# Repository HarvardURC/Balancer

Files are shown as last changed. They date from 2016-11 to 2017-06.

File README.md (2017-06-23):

# Balancer
Repository for the Harvard Undergraduate Robotics Club's Balancer team

# CAD_Files
Contains CAD files used to create the Balancer. 

- 1X CAD contains files used to create our original Balancer
- 1.5X CAD contains files used to create our Balancer scaled up by 50%

# Final_Code
Contains our final competition code.

# Old NRF Code (also Filtering)
Contains deprecated code when from we used NRF communication protocol. Also contains deprecated code which used a complementary filter to smooth BNO sensor data. 

# Telemetry
Contains the TelemetryViewer app and txt files to setup our telemetry environment.

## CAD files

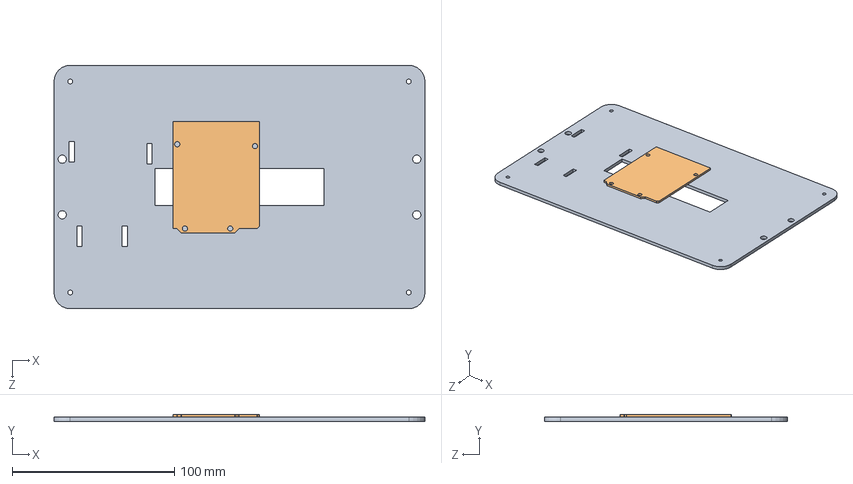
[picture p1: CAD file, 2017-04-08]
CAD_Files/1.5x CAD/new_layer.SLDASM
228.6 x 4.19 x 150.0 mm
new_layer
Arduino

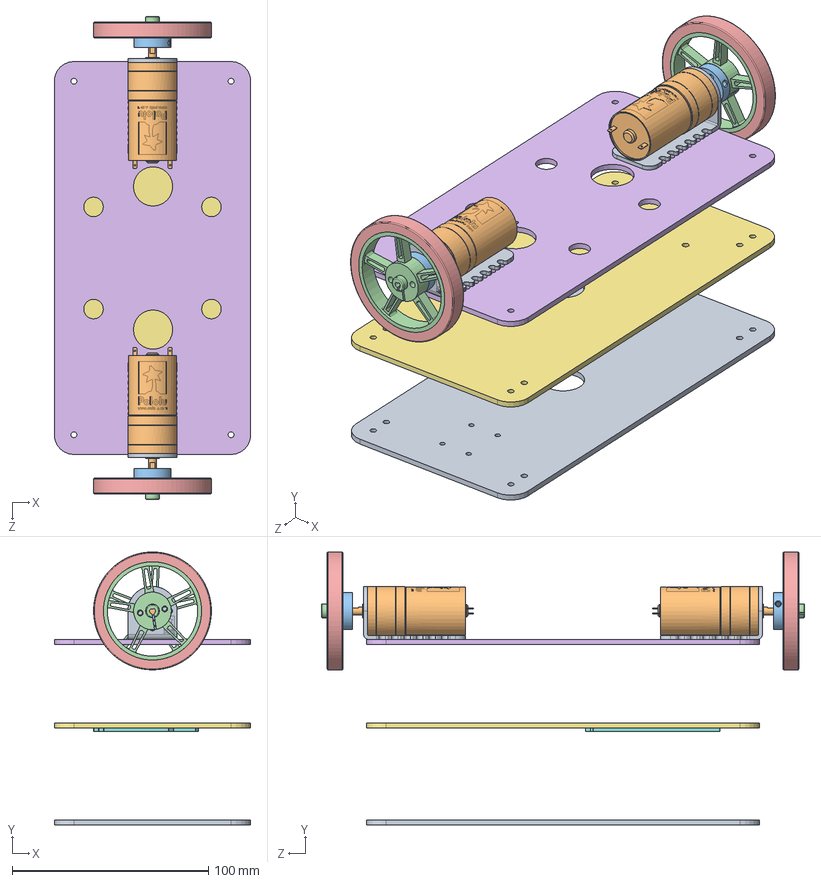
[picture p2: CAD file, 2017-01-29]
CAD_Files/1X CAD/full assembly.SLDASM
100.0 x 138.9 x 246.1 mm
motor mount x 2
motor x 2
mounting hub x 2
Part2^pololu wheel x 2
Part3^pololu wheel x 2
top
mid
Arduino
3rd layer

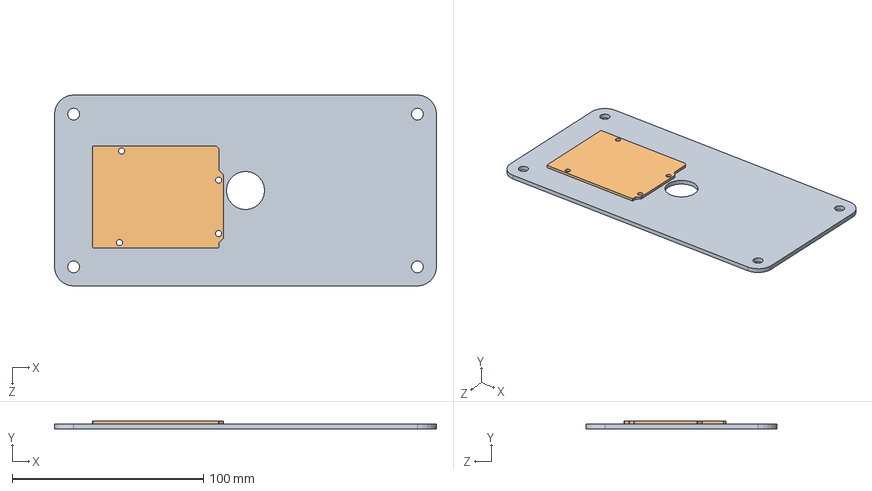
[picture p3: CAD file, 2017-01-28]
CAD_Files/1X CAD/mid assembly.SLDASM
200.0 x 4.19 x 100.0 mm
mid
Arduino

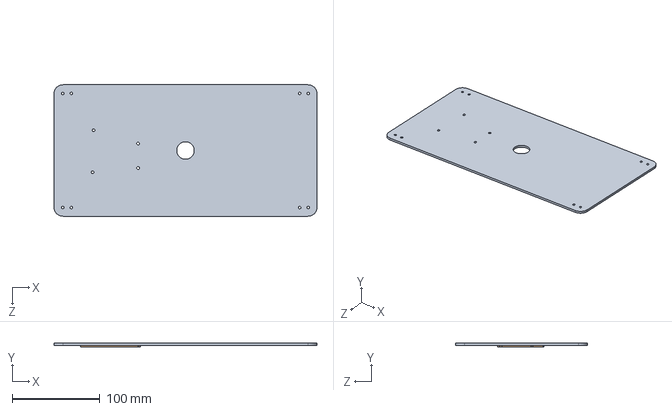
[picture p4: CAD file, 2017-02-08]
CAD_Files/1.5x CAD/mid assembly.SLDASM
300.0 x 4.19 x 150.0 mm
mid
Arduino

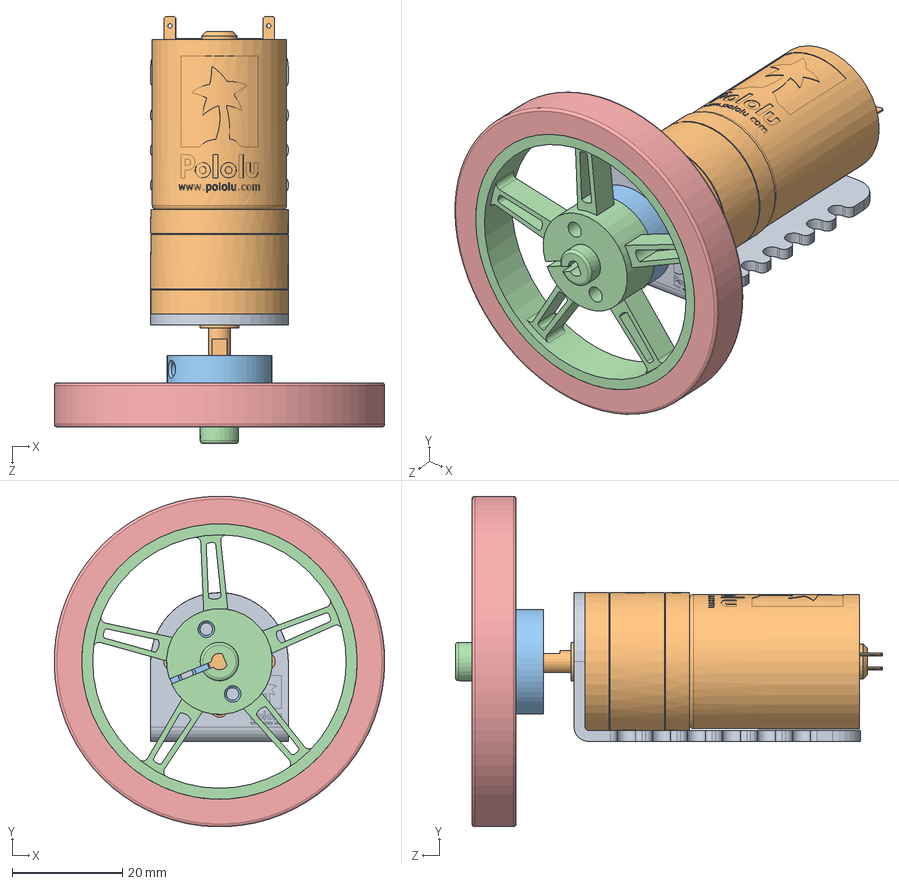
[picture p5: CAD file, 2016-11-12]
CAD_Files/1X CAD/motor full assembly.SLDASM
60.0 x 60.0 x 77.5 mm
motor mount
motor
mounting hub
Part2^pololu wheel
Part3^pololu wheel

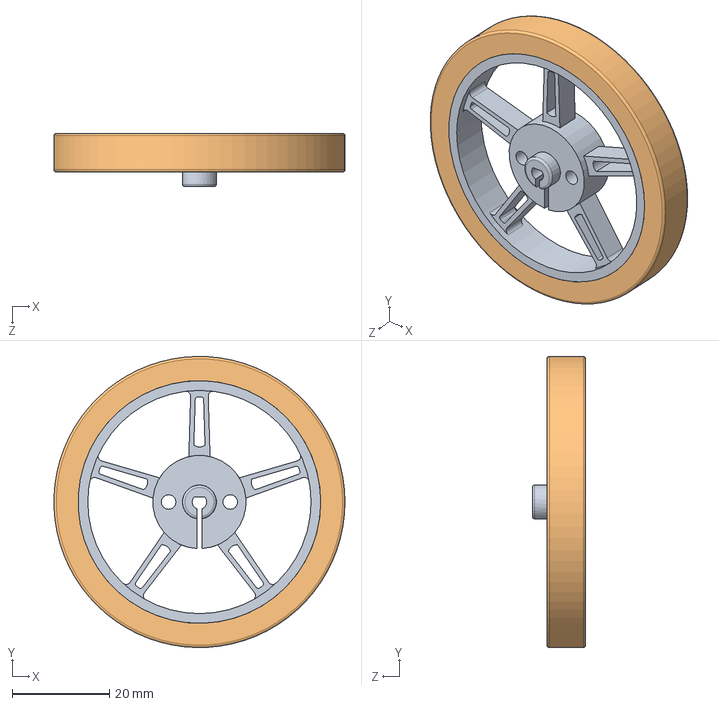
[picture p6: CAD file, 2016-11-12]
CAD_Files/1X CAD/pololu wheel.SLDASM
60.0 x 60.0 x 11.0 mm
Part2^PololuWheel 60x8mm
Part3^PololuWheel 60x8mm

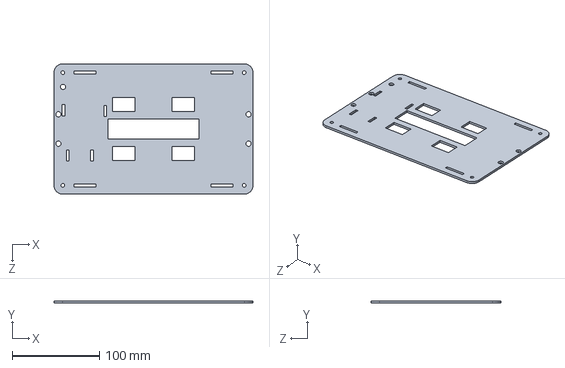
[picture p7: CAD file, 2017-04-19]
CAD_Files/1.5x CAD/final_layer_2.SLDPRT
228.6 x 2.60 x 149.9 mm

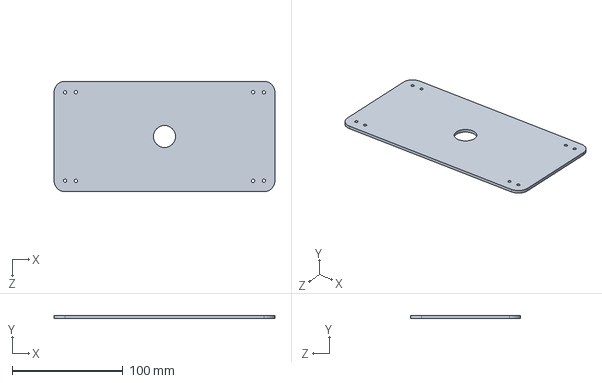
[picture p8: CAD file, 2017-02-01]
CAD_Files/1X CAD/4th layer.SLDPRT
200.0 x 2.60 x 100.0 mm

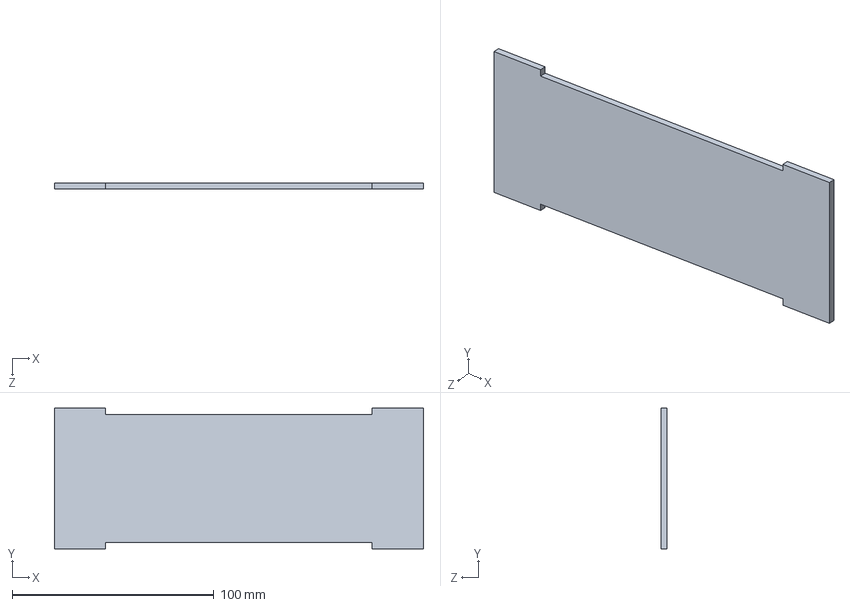
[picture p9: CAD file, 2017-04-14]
CAD_Files/1.5x CAD/sideplate.SLDPRT
182.9 x 69.8 x 3.17 mm

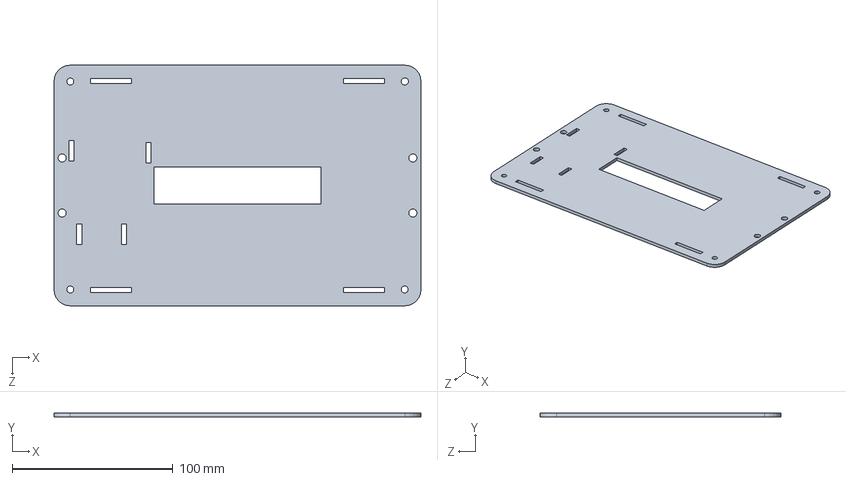
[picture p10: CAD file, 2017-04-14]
CAD_Files/1.5x CAD/final_layer.SLDPRT
228.6 x 2.60 x 149.9 mm

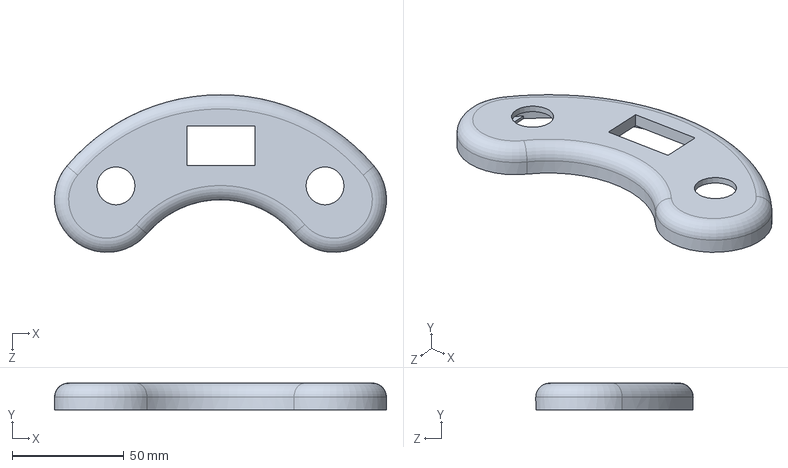
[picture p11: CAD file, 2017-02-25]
CAD_Files/1.5x CAD/Controller.SLDPRT
148.5 x 12.1 x 70.5 mm

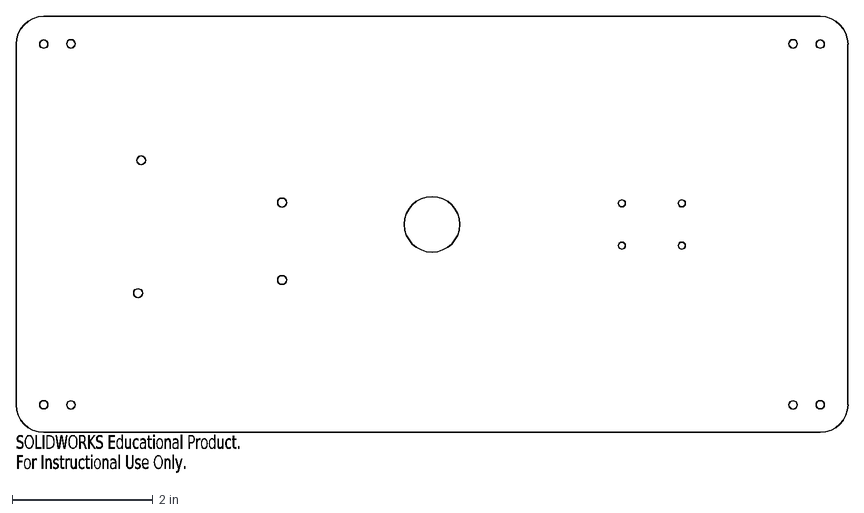
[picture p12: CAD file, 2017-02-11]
CAD_Files/1.5x CAD/ArduinoLayer.DXF
SOLIDWORKS Educational Product.
For Instructional Use Only.

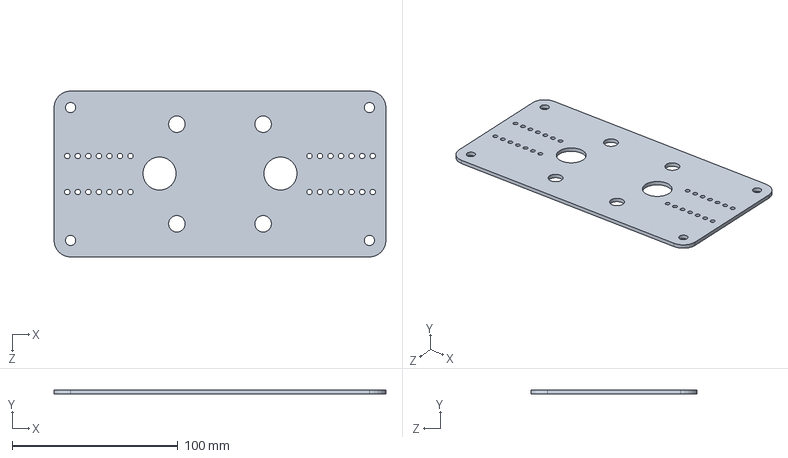
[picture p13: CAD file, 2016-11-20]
CAD_Files/1X CAD/top.SLDPRT
200.0 x 2.60 x 100.0 mm

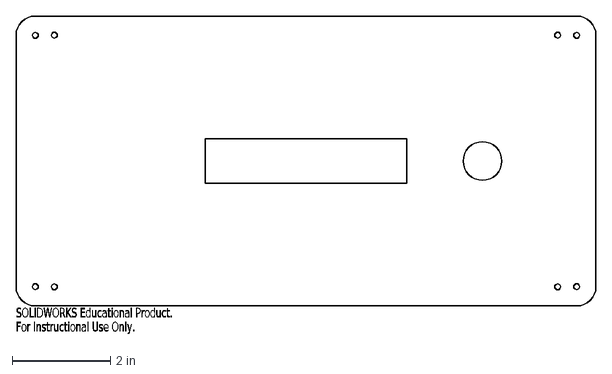
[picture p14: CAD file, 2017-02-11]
CAD_Files/1.5x CAD/Battery Layer.DXF
SOLIDWORKS Educational Product.
For Instructional Use Only.

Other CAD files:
CAD_Files/1X CAD/mid.SLDPRT
CAD_Files/1X CAD/3rd layer.SLDPRT
CAD_Files/1X CAD/spacer.SLDPRT
CAD_Files/1.5x CAD/Empty.DXF
CAD_Files/1.5x CAD/3rd layer.SLDPRT
CAD_Files/1.5x CAD/4th layer.SLDPRT
CAD_Files/1.5x CAD/Arduino.SLDPRT
CAD_Files/1.5x CAD/Motor Layer.DXF
CAD_Files/1.5x CAD/final_layer.DXF
CAD_Files/1.5x CAD/final_layer_2.DXF
CAD_Files/1.5x CAD/mid.SLDPRT
CAD_Files/1.5x CAD/new_layer.DXF
CAD_Files/1.5x CAD/sideplate.DXF
CAD_Files/1.5x CAD/top.SLDPRT
CAD_Files/1X CAD/Arduino.SLDPRT
CAD_Files/1X CAD/motor mount.SLDPRT
CAD_Files/1X CAD/motor.SLDPRT
CAD_Files/1X CAD/mounting hub.SLDPRT
CAD_Files/1X CAD/top.DXF

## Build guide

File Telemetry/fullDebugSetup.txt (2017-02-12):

Telemetry Viewer File Format v0.1

Grid Settings:

	column count = 16
	row count = 15

Serial Port Settings:

	port = cu.usbmodem1411
	baud = 115200
	packet type = ASCII CSVs
	sample rate = 10000

15 Data Structure Locations:

	location = 0
	processor index = 0
	name = accel_x
	color = 0xFF0000
	unit = 
	conversion factor a = 1.0
	conversion factor b = 1.0

	location = 1
	processor index = 0
	name = accel_y
	color = 0x33FF33
	unit = 
	conversion factor a = 1.0
	conversion factor b = 1.0

	location = 2
	processor index = 0
	name = accel_z
	color = 0x0000FF
	unit = 
	conversion factor a = 1.0
	conversion factor b = 1.0

	location = 3
	processor index = 0
	name = gyro_x
	color = 0xFF3333
	unit = 
	conversion factor a = 1.0
	conversion factor b = 1.0

	location = 4
	processor index = 0
	name = gyro_y
	color = 0x33FF33
	unit = 
	conversion factor a = 1.0
	conversion factor b = 1.0

	location = 5
	processor index = 0
	name = gyro_z
	color = 0x0000FF
	unit = 
	conversion factor a = 1.0
	conversion factor b = 1.0

	location = 6
	processor index = 0
	name = mag_x
	color = 0xFF3333
	unit = 
	conversion factor a = 1.0
	conversion factor b = 1.0

	location = 7
	processor index = 0
	name = mag_y
	color = 0x33FF33
	unit = 
	conversion factor a = 1.0
	conversion factor b = 1.0

	location = 8
	processor index = 0
	name = mag_z
	color = 0x0000FF
	unit = 
	conversion factor a = 1.0
	conversion factor b = 1.0

	location = 9
	processor index = 0
	name = pitch
	color = 0xFF33FF
	unit = 
	conversion factor a = 1.0
	conversion factor b = 1.0

	location = 10
	processor index = 0
	name = setPoint
	color = 0x000000
	unit = 
	conversion factor a = 1.0
	conversion factor b = 1.0

	location = 11
	processor index = 0
	name = output
	color = 0x000000
	unit = 
	conversion factor a = 1.0
	conversion factor b = 1.0

	location = 12
	processor index = 0
	name = kP
	color = 0xFF3333
	unit = 
	conversion factor a = 1.0
	conversion factor b = 1.0

	location = 13
	processor index = 0
	name = kI
	color = 0x33FF33
	unit = 
	conversion factor a = 1.0
	conversion factor b = 1.0

	location = 14
	processor index = 0
	name = kD
	color = 0x3333FF
	unit = 
	conversion factor a = 1.0
	conversion factor b = 1.0

6 Charts:

	chart type = Time Domain Chart (Cached)
	duration = 1000
	top left x = 0
	top left y = 0
	bottom right x = 6
	bottom right y = 4
	datasets count = 3
		dataset location = 0
		dataset location = 1
		dataset location = 2

	chart type = Time Domain Chart (Cached)
	duration = 1000
	top left x = 0
	top left y = 5
	bottom right x = 6
	bottom right y = 9
	datasets count = 3
		dataset location = 3
		dataset location = 4
		dataset location = 5

	chart type = Time Domain Chart (Cached)
	duration = 1000
	top left x = 0
	top left y = 10
	bottom right x = 6
	bottom right y = 14
	datasets count = 3
		dataset location = 6
		dataset location = 7
		dataset location = 8

	chart type = Time Domain Chart (Cached)
	duration = 1000
	top left x = 7
	top left y = 0
	bottom right x = 15
	bottom right y = 8
	datasets count = 2
		dataset location = 9
		dataset location = 10

	chart type = Dial Chart
	duration = 1000
	top left x = 7
	top left y = 9
	bottom right x = 10
	bottom right y = 14
	datasets count = 1
		dataset location = 9

	chart type = Time Domain Chart (Cached)
	duration = 1000
	top left x = 11
	top left y = 9
	bottom right x = 15
	bottom right y = 14
	datasets count = 4
		dataset location = 11
		dataset location = 12
		dataset location = 13
		dataset location = 14

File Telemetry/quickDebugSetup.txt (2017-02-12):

Telemetry Viewer File Format v0.1

Grid Settings:

	column count = 16
	row count = 16

Serial Port Settings:

	port = cu.usbmodem1411
	baud = 115200
	packet type = ASCII CSVs
	sample rate = 10000

15 Data Structure Locations:

	location = 0
	processor index = 0
	name = accel_x
	color = 0xFF0000
	unit = 
	conversion factor a = 1.0
	conversion factor b = 1.0

	location = 1
	processor index = 0
	name = accel_y
	color = 0x33FF33
	unit = 
	conversion factor a = 1.0
	conversion factor b = 1.0

	location = 2
	processor index = 0
	name = accel_z
	color = 0x0000FF
	unit = 
	conversion factor a = 1.0
	conversion factor b = 1.0

	location = 3
	processor index = 0
	name = gyro_x
	color = 0xFF3333
	unit = 
	conversion factor a = 1.0
	conversion factor b = 1.0

	location = 4
	processor index = 0
	name = gyro_y
	color = 0x33FF33
	unit = 
	conversion factor a = 1.0
	conversion factor b = 1.0

	location = 5
	processor index = 0
	name = gyro_z
	color = 0x0000FF
	unit = 
	conversion factor a = 1.0
	conversion factor b = 1.0

	location = 6
	processor index = 0
	name = mag_x
	color = 0xFF3333
	unit = 
	conversion factor a = 1.0
	conversion factor b = 1.0

	location = 7
	processor index = 0
	name = mag_y
	color = 0x33FF33
	unit = 
	conversion factor a = 1.0
	conversion factor b = 1.0

	location = 8
	processor index = 0
	name = mag_z
	color = 0x0000FF
	unit = 
	conversion factor a = 1.0
	conversion factor b = 1.0

	location = 9
	processor index = 0
	name = pitch
	color = 0xFF33FF
	unit = 
	conversion factor a = 1.0
	conversion factor b = 1.0

	location = 10
	processor index = 0
	name = setPoint
	color = 0x000000
	unit = 
	conversion factor a = 1.0
	conversion factor b = 1.0

	location = 11
	processor index = 0
	name = output
	color = 0x000000
	unit = 
	conversion factor a = 1.0
	conversion factor b = 1.0

	location = 12
	processor index = 0
	name = kP
	color = 0xFF3333
	unit = 
	conversion factor a = 1.0
	conversion factor b = 1.0

	location = 13
	processor index = 0
	name = kI
	color = 0x33FF33
	unit = 
	conversion factor a = 1.0
	conversion factor b = 1.0

	location = 14
	processor index = 0
	name = kD
	color = 0x3333FF
	unit = 
	conversion factor a = 1.0
	conversion factor b = 1.0

3 Charts:

	chart type = Time Domain Chart (Cached)
	duration = 1000
	top left x = 0
	top left y = 0
	bottom right x = 15
	bottom right y = 9
	datasets count = 2
		dataset location = 9
		dataset location = 10

	chart type = Dial Chart
	duration = 1000
	top left x = 0
	top left y = 10
	bottom right x = 4
	bottom right y = 15
	datasets count = 1
		dataset location = 9

	chart type = Time Domain Chart
	duration = 1000
	top left x = 5
	top left y = 10
	bottom right x = 15
	bottom right y = 15
	datasets count = 4
		dataset location = 11
		dataset location = 12
		dataset location = 13
		dataset location = 14

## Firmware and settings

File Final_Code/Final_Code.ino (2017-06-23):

// necessary includes
#include "DualVNH5019MotorShield.h"
#include <Adafruit_BNO055.h>
#include <utility/imumaths.h>
#include <PID_v1.h>
#include <SSD1306_text.h>

// OLED setup
#define OLED_RESET 1
SSD1306_text display(OLED_RESET);

// define joystick pins
#define UP_DOWN_IN_PIN   3 
#define  LEFT_RIGHT_IN_PIN  5

// encoder pins for interrupts
#define SPD_INT_L A2
#define SPD_PUL_L A1
#define SPD_INT_R A3
#define SPD_PUL_R A4

// Set the delay between fresh samples
#define BNO055_SAMPLERATE_DELAY_MS (10)

// PID match PWM max in reverse and foward
#define BALANCE_PID_MIN -255
#define BALANCE_PID_MAX 255

// Need to call constructor differently for Arduino zero
Adafruit_BNO055 bno = Adafruit_BNO055(55, 0x29);

// normal constructor call:
// Adafruit_BNO055 bno = Adafruit_BNO055();

DualVNH5019MotorShield md;

// PID object and required PID globals
double output, pitch, setPoint, send_pitch;
 
float kP = 3.3;//6.3; //6.9;
float kI = 0.0;//0.02;//0.02;
float kD = 0.07;//0.10;//0.11;
float kPwheel = 1.5;
float kDwheel = 0;//0.05;

PID pid(&pitch, &output, &setPoint, kP, kI, kD, AUTOMATIC);

// globals
int Speed_L = 0;
int Speed_R = 0;
int last_countL = 0;
int last_countR = 0;

int right_stick, left_stick;
float turn_val;
int potPin = A0;
long potVal = 0.0;
float y_val = 0;
bool stop_flag = false; 

// Compensate for motor slack range 
// (low PWM values which result in no motor engagement)
float MOTORSLACK_M1 = 5;	
float MOTORSLACK_M2 = 8;


/* "center" defines the joystick value that is read when the balancer
 *  is at 0 degrees. Not precisely 0 because of uneven weight
 *  distribution. -1325 -> -1.325 degrees
 *  "delta" defines the max/min degrees the robot will tilt when moving
 *  in this case 4 degrees (4000 -> 4.000 degrees)
 */
#define center -1325
#define delta 4000

void setup()
{
	// Serial Setup
	Serial.begin(115200);
	Serial.setTimeout(10);

	// RC Receiving Pins Setup
	pinMode(3, INPUT); // Set our input pins as such
	pinMode(5, INPUT);
	pinMode(0, INPUT);

	pinMode(A1, INPUT);
	pinMode(A2, INPUT);
	pinMode(A3, INPUT);
	pinMode(A4, INPUT);
	pinMode(A5, OUTPUT);	

	// enable pull-up resistors
	digitalWrite(A1, HIGH);
	digitalWrite(A2, HIGH);
	digitalWrite(A3, HIGH);
	digitalWrite(A4, HIGH);
	digitalWrite(A5, HIGH);

	// create ISR's (interrupt service routines) 
	attachInterrupt(SPD_PUL_L, Encoder_L, CHANGE);
 	attachInterrupt(SPD_PUL_R, Encoder_R, CHANGE);


	// OLED setup
    display.init();
    display.clear();
    
    // dualvnh lib for motor controller
	md.init();	

	Serial.println("Orientation Sensor Raw Data Test");
	Serial.println("");

	/* Initialize the IMU (exmaple code) */
	if (!bno.begin())
	{
	/* There was a problem detecting the BNO055 ... check your connections */
		Serial.print("No BNO055 detected, check wiring / I2C ADDR");
		while (1);
	}

	bno.setExtCrystalUse(true);

	// our setpoint for the pid loop
	setPoint = .10 ;

	// Arduino PID Library setups
	pid.SetMode(AUTOMATIC);
	pid.SetOutputLimits(-255, 255);
	pid.SetSampleTime(10);
}

void loop()
{
	// read the pulse width of each channel
	left_stick = pulseIn(5, HIGH);
	right_stick = pulseIn(3, HIGH);

	// robot should be stopped unless told otherwise
	stop_flag = true;

	// robot is allowed to balance at non-0 degree angles
	if (pulseIn(0, HIGH, 25000) < 1500)
	{
		stop_flag = false;
	}

	// map input joystick values to desired setpoint values
	left_stick = map(left_stick, 950, 2050, center - delta, center + delta);
	
	// deadzone 
	int error = 65;
	if(left_stick < (center + error) && left_stick > (center - error))
	{
		left_stick = center;
	}
	
	setPoint = left_stick;

	// map right joystick for turning (set a difference in L vs R motor values) 
	y_val = (map(right_stick, 950,2050,-15000.0, 15000));
	
	setPoint = setPoint / 1000.0;
	y_val = y_val / 1000.0;

	
	potVal = analogRead(potPin);
	
	// uncomment 1 of below to tune the respective values with potentiometer
//	kP = map(potVal, 0, 1023, 0, 10000);
//	kP = kP / 1000.0;
//	kD = map(potVal, 0, 1023, 0, 1000);
//	kD = kD / 1000.0;
//	kI = map(potVal, 0, 1023, 0, 100);
//	kI = kI / 1000.0;
//	pid.SetTunings(kP, kI, kD);
//	setPoint = map(potVal, 0, 1023, -3000, 3000);
//	setPoint = setPoint / 1000.0; 

	// IMU values
	imu::Vector<3> euler = bno.getVector(Adafruit_BNO055::VECTOR_EULER);

	// get the z orientation
	pitch = euler.y();

	// if we're out of control stop motors
	if (abs(pitch) > 45)
	{
		md.setM1Speed(0);
		md.setM2Speed(0);
	}
	else
	{
		// use pid loop to calculate output
		pid.Compute(); 
		
		// if we're supposed to be moving, factor in the wheel constants
		double output1 = compensate_slack(-output, 1); //M1
		double output2 = compensate_slack(-output, 0); //M2
		
		if (!stop_flag)
		{
			// average of two encoder rates
			float speed_avg = (Speed_R + Speed_L) / 2;
			// final output as combination of IMU PID and encoder PID
			output1 = output1 + 
				(kPwheel * Speed_L) + (kDwheel * abs(Speed_L - last_countL));
			output2 = output2 + 
				(kPwheel * Speed_R) + (kDwheel * abs(Speed_R - last_countR));
				
			md.setM1Speed(output1);
			md.setM2Speed(output2);
		}
		
		// for derivative next loop
		last_countL = Speed_L;
		last_countR = Speed_R;

		// if we're supposed to be stationary, ignore encoder readings
		if (stop_flag) 
		{
			md.setM1Speed(output1);
			md.setM2Speed(output2);
		}

		//overwrite stationary command if we want to turn
		if (y_val > 1.0) 
		{
			md.setM1Speed(output1 + 25);
			md.setM2Speed(output2 - 25);
		}
		else if (y_val < -1.0)
		{
			md.setM1Speed(output1 - 25);
			md.setM2Speed(output2 + 25);
		}
		
	}
	// debug 
	/*
	display.setCursor(0,40);
    display.setTextSize(2,1);
    display.print(setPoint,3);

    display.setCursor(4,40);
    display.print(kP,3);
    
    display.setCursor(6,40);
    display.print(pitch,3);

    display.print(y_val,3);
	*/

	// reset encoder rates
	Speed_L = 0;
	Speed_R = 0;
}

/* CREDIT ManpreetSingh80 on Github
https://github.com/ManpreetSingh80/CHAPPIE/blob/master/SelfBalance_robot0
_66_withoutEEPROM/SelfBalance_robot0_66_withoutEEPROM.ino
*/
double compensate_slack(double Output, bool A)
{
// Compensate for DC motor non-linear "dead" zone around 0 where small values 
// don't result in movement
// Output is desired output before compensation, the boolean lets us know which 
// motor's slack to use
	if (A)
	{
		if (Output > 0)
		{
			Output += MOTORSLACK_M1;
		}
		else
		{
			Output -= MOTORSLACK_M1;
		}
	}
	else
	{
		if (Output > 0)
		{
			Output += MOTORSLACK_M2;
		}
		else
		{
			Output -= MOTORSLACK_M2;
		}
	}

	// ensure output remains within bounds of the motor sets
	Output = constrain(Output, BALANCE_PID_MIN, BALANCE_PID_MAX);
	return Output;
}

void Encoder_L()   //car up is positive car down  is negative
{
  if (digitalRead(SPD_PUL_L) == digitalRead(SPD_INT_L))
    Speed_L++;
  else
    Speed_L--;
}


void Encoder_R()    //car up is positive car down  is negative
{
  if (digitalRead(SPD_PUL_R) == digitalRead(SPD_INT_R))
    Speed_R++;
  else
    Speed_R--;
}

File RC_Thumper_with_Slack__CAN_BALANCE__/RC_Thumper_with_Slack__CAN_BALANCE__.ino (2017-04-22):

//TODO: Turning is bizarre... almost "incrememnts" every time hit throttle in that direction
// TODO: ALso, to get rid of crazy mvmt get rid of print statemnets
#include "DualVNH5019MotorShield.h"
#include <Wire.h>
#include <Adafruit_Sensor.h>
#include <Adafruit_BNO055.h>
#include <utility/imumaths.h>
#include <PID_v1.h>
#include <SPI.h>
#include <avr/dtostrf.h>
#define transmit_buffer 10
#define receive_buffer 10
#include <Adafruit_GFX.h>
#include <Adafruit_SSD1306.h>
#include <SSD1306_text.h>

#define OLED_RESET 1
SSD1306_text display(OLED_RESET);

#define UP_DOWN_IN_PIN   3   //maybe flip these 2
#define  LEFT_RIGHT_IN_PIN  5

#define SPD_INT_L A2   //interrupt 
#define SPD_PUL_L A1   
#define SPD_INT_R A3   //interrupt 
#define SPD_PUL_R A4   

int Speed_L = 0;
int Speed_R = 0;
int Speed_Avg = 0;
int last_count = 0;
// http://maniacbug.github.io/RF24/classRF24.html#a391eb0016877ec7486936795aed3b5ee
// radio variables
const uint64_t pipe = 0xF0F0F0F0AA;

int right_stick, left_stick;
float turn_val;
/*
  CREDIT: ARDUINO BNO055 EXAMPLE CODE
*/

// Set the delay between fresh samples
#define BNO055_SAMPLERATE_DELAY_MS (10)

// PID match PWM max in reverse and foward
#define BALANCE_PID_MIN -255
#define BALANCE_PID_MAX 255

// Need to call constructor differently for Arduino zero
Adafruit_BNO055 bno = Adafruit_BNO055(55, 0x29);

// normal constructor call:
// Adafruit_BNO055 bno = Adafruit_BNO055();

DualVNH5019MotorShield md;

/* PID object and required globals */

double output, pitch, setPoint, send_pitch;

// pid consts used with serial input to modify constants

// NEWEST BESTEST W/ R?C
// 8-11 possible kp w/o slack
// ?-? possible kpw/ slack
//float kP = 6.3;
//float kI = 0.0;
//float kD = 0.18;
// NEWEST BESTEST W/ R?C
// 8-11 possible kp w/o slack
// ?-? possible kpw/ slack
float kP = 6.3;
float kI = 0;
float kD = 0.10;
float kPwheel = 0.0;
float kDwheel = 0.00;
// ----------------
// -----------------------------------------

PID pid(&pitch, &output, &setPoint, kP, kI, kD, AUTOMATIC);


int potPin = 0;
long potVal = 0.0;
// was 65/60
//float MOTORSLACK_1 = 26.5;	// Compensate for motor slack range (low PWM values which result in no motor engagement)
//float MOTORSLACK_2 = 25;	// Compensate for motor slack range (low PWM values which result in no motor engagement)

float MOTORSLACK_M1 = 5;	// Compensate for motor slack range (low PWM values which result in no motor engagement)
float MOTORSLACK_M2 = 7;	// Compensate for motor slack range (low PWM values which result in no motor engagement)


// timer setup: we're running on a 10 ms loop
long previousMillis = 0;
unsigned long currentMillis;
long interval = 10;
float y_val = 0;

/**************************************************************************/
/*
    Arduino setup function (automatically called at startup)
*/
/**************************************************************************/

#define center -1050
#define delta 2000

void setup()
{
	// Serial Setup
	Serial.begin(115200);  // serial for debug
	Serial.setTimeout(10);

	// RC Receiving Pins Setup
	pinMode(3, INPUT); // Set our input pins as such
	pinMode(5, INPUT);

	// OLED setup
    display.init();
    display.clear();                 // clear screen

	md.init();	// dualvnh lib for motor controller

	Serial.println("Orientation Sensor Raw Data Test");
	Serial.println("");

	/* Initialize the sensor */
	if (!bno.begin())
	{
		/* There was a problem detecting the BNO055 ... check your connections */
		Serial.print("Ooops, no BNO055 detected ... Check your wiring or I2C ADDR!");
		while (1);
	}

	bno.setExtCrystalUse(true);

	// our setpoint for the pid loop
	setPoint = -1.0 ; //BETTER @ 3.5? 3.2 is 0, 2.9 used to be 0

	// Arduino PID Library setups
	pid.SetMode(AUTOMATIC);
	pid.SetOutputLimits(-255, 255);
	pid.SetSampleTime(10);


	attachInterrupt(SPD_INT_L, Encoder_L, RISING); // pin 2
  	attachInterrupt(SPD_INT_R, Encoder_R, RISING); // pin 3	

	// radio setup
	Serial.println("BEGIN"); 
}
// get new gyro data


void loop()
{
	//950 -> 2050
	left_stick = pulseIn(5, HIGH, 25000); // each channel
	right_stick = pulseIn(3, HIGH, 25000); // Read the pulse width of 

	//Serial.println(right_stick);
	left_stick = map(left_stick, 950, 2050, center - delta, center + delta + 500);
	setPoint = left_stick;
	y_val = (map(right_stick, 950,2050,-15000.0, 15000));
	setPoint = setPoint / 1000.0;
	y_val = y_val / 1000.0;

	pid.SetTunings(kP, kI, kD);
	
	
//	Serial.println(left_stick);
//	Serial.println(map(left_stick, 950,2050,-20,20)); // ctr @ 0 and turning

	//Serial.println(map(right_stick, 950,2050,-20,20)); // ctr @ 0 and turning

    //Serial.println(ch1);
	potVal = analogRead(potPin);
//	kP = map(potVal, 0, 1023, -20000, 10000);
//	kP = kP / 1000.0;
//	kD = map(potVal, 0, 1023, -1000, 1000);
//	kD = kD / 1000.0;
//	setPoint = map(potVal, 0, 1023, -3000, 3000);
//	setPoint = setPoint / 1000.0; 
	imu::Vector<3> euler = bno.getVector(Adafruit_BNO055::VECTOR_EULER);

		// get the z orientation
		pitch = euler.y();

		// if z has changed update pos. and find which direction we rotated
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

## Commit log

2016-11-10 Initial Balancer P-Controller
    Basic conceptual P-Controller for initial balancing tests. Changed the way the constructor was called for the IMU to work with the Arduino Zero. Changed the map() values for preliminary balancing tes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
2016-11-12 top layer finished + all cad files
    [Arduino.SLDPRT, full assembly.SLDASM, mid assembly.SLDASM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]
2016-11-13 Adding Folder for CAD Files
2016-11-13 Moved CAD files into separate folder
    [Arduino.SLDPRT, full assembly.SLDASM, mid assembly.SLDASM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]
2016-11-15 Mid and Top Layer flush with each other
    [full assembly.SLDASM]
2016-11-20 added spacers
    [full assembly.SLDASM]
2016-11-20 New assembly w/ battery
    [full assembly.SLDASM]
2016-12-31 Full PID with Sensor Fusion Data and Consistent Update Cycle Code now correctly uses BNO055 sensor's fusion data. Also compensates for motor backlash by adding two "MOTORSLACK" variables to finished 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
2017-01-29 Increased distance between holes
    [3rd layer.SLDPRT, full assembly.SLDASM, mid.SLDPRT]
2017-01-29 Added spacer to CAD files
    [spacer.SLDPRT]
2017-01-29 Moved spacer
    [spacer.SLDPRT]
2017-02-01 Added 4th layer
    [4th layer.SLDPRT]
2017-02-08 wireless_receiver code
2017-02-08 wireless_sender code
2017-02-08 Uploaded new CAD files
    [3rd layer.SLDPRT, 4th layer.SLDPRT, Arduino.SLDPRT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]
2017-02-11 Uploaded .dxf
    [ArduinoLayer.DXF, Battery Layer.DXF, Empty.DXF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]
2017-02-12 Allow PID Full Control Over Setting Motor Direction (+/-) Got rid of enc_direction variable and method of passing in the absolute value of the current angle to the PID. The PID now determines for its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
2017-02-12 Modify PID Constants With Serial Input Added functionality to allow user to send new PID constants to the Arduino mid- testing over serial communication. Send constants in the form: kP,kI,kD
2017-02-12 Graphing Functionality (visualization CREDIT: farrellf) Added functionality for convenient data visualization. Code changes include new print statements in comma separated format. Added a new file, T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
2017-02-12 Telemetry Tests and Configuration Files Added configuration files for telemetry tests. These txt files can be loaded from the telemetry applet, and contain graphing setups which will be useful. quick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
    [log.csv]
2017-02-12 Pushing current work-in progress code at John's request
    [log.csv]
2017-02-12 Updated Compensate_Slack for New Motors, More Tuning. Also got rid of sending absolute value to the PID, and got rid of the second "zero" point.
2017-02-15 Battery layer
    [3rd layer.SLDPRT]
2017-02-17 Created New Code that Uses Gyro Data. Instead of using full IMU fusion data, which was proving unreliable, this code uses just the gyroscope data, which is proving to be more accurate so far.
2017-02-18 Added controller
    [Controller.SLDPRT]
2017-02-18 Controller updated
    [Controller.SLDPRT]
2017-02-22 Updated controller
    [Controller.SLDPRT]
2017-02-25 Added Framework for 2-Way Comms
2017-02-25 2-Way Wireless Communication Functional Currently uses joystick's button sensor. Attach the button sensor to one of the two Arduinos. When the button is clicked, the arduino attached with that button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
2017-03-04 Start of Raw Data + Complementary Filter Approach
2017-03-04 Correct Gyro Axis
2017-03-04 Complementary Filter Running. Currently, robot response time seems slow. Will investigate the author of the used complementary filter's choice of time units, which seems strange (calling Arduino mill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
2017-03-05 joystick wireless
    [3rd layer.SLDPRT, 4th layer.SLDPRT, Arduino.SLDPRT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]
2017-03-25 Current Working Code in Gyro_PID_Controller
2017-03-31 Wireless Data Logging and Setpoint Changing Thumper can move!! (Code is a little messy because committing right before heading out)
    [log.csv]
2017-04-05 (REVERT BEFORE THIS) Ugly Printing to Find Slowdown
    [wireless_2-way.ino]
2017-04-05 Modified Layer
    [new_layer.DXF, new_layer.SLDASM]
2017-04-09 Final for 8-32
    [final_layer.DXF, final_layer.SLDPRT, sideplate.DXF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]
2017-04-16 Fixed New Thumper Code
    [wireless_2-way.ino]
2017-04-16 Thumper Can Drive and Tune PID with Pot
2017-04-19 testing code-with encoder
2017-04-19 compiles + encoder fix
2017-04-20 pid tuning
2017-04-21 Tuning Current Drive Code
2017-04-22 Pushing Current Competition Code
2017-06-23 Codebase Cleanup and Documentation
    [3rd layer.SLDPRT, 4th layer.SLDPRT, Arduino.SLDPRT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]
